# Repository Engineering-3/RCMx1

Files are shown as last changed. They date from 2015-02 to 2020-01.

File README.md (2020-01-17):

RCMx1
========================

RCMx1

This is an interface board for the RCM Control Stack that accommodates inputs (sensors) and outputs (motors, servos, LEDs) and communication through UART, SPI and I2C. Please see [Engineering3](http://engineering3.org/) for more information on the complete RCM Control Stack project.

Repository Contents
-------------------

* **/board** Eagle schematic/board files, gerbers, BOM
* **/firmware** Microcontroller firmware build files

Version History
---------------
* [RCMx1 Board v03](https://github.com/Engineering-3/RCMx1/tree/master/board/RCMx1_v03) First public hardware version - version 3 
* [RCMx1 Firmware v07](https://github.com/Engineering-3/RCMx1/tree/master/firmware) First public firmware version - version 7

License Information
-------------------
Hardware is released under [Solderpad Hardware License v0.51](http://solderpad.org/licenses/SHL-0.51/).
Firmware is released under [GNU GPL v2](http://www.gnu.org/licenses/old-licenses/gpl-2.0.html).
Distributed as-is; no warranty is given.

Getting Started Help
--------------------
Follow the [RCMx1 User Guide](https://github.com/Engineering-3/RCMx1/blob/master/firmware/docs/RCMx1%20User%20Guide.doc) here in the repo.

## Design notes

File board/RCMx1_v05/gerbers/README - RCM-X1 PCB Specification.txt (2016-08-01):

RCM-X1 PCB Specification
-------------------------------

BOARD STACK:

1. Copper Top
2. Copper Bottom

SILKSCREENS:

1.  Both Layers

PASTE MASKS:

1. Top Layer

BOARD MATERIALS:

RoHS Compliant: YES
Copper: 1oz
Finish: Immersion Gold
Material: FR-406
Thickness: 62 mil
Tg>170
Soldermask: SMOBC BLUE
Silkscreen: White

BOARD TESTING:

Electrical Test: YES

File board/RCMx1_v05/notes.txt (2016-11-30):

Got version RCMx1_v01 from Tim (who got it from Jim) - 10/29/2014.

Updated to v02 with the following changes: (10/29/2014 - BPS - Schmalz Haus)
* Changed fiducal marks so they had the copper restrict layer pulling back the copper the full 0.04".
* Changed R19 from 499K to 499 ohms (error only in DigiKey Part Number field of BOM)

Updated to v03 with the following changes: (02/13/2015 - BPS - Schmalz Haus)
* Added OSHW logo to schematic and board silk layer (done)
* Added Solderpad license to schematic (done)
* Added Copyright to schematic and silk layer (done)
* Added ROSH symbol to board silk layer (done)

Updated to v04 with the following changes: (02/28/2016 - BPS - Schmalz Haus)
* Added OSHW logo to the bottom silk layer
* Added RoSH symbol to the bottom silk layer
* Added "http://engineering3.org" and "RoSH Compliant" to bottom silk layer
* Updated rev text on top silk
* Updated copyright dates to 2016 on schematic and board silk

Updated to v05 with the following changes: (11/29/2016 - BPS - Schmalz Haus)
* Fixed pin one silk screen for J7 (ICSP header)

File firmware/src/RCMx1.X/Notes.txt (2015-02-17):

Notes on RCMx1 when doing firmware bringup.

* Wrong processor used - need the larger part (get part number for Jim) with PWM 9 and 10
* Silk screen for GPIO and Analog needs to be re-thought
* Mapping of analog and GPIO needs to be updated - create map of current code for Tim and approve
* ADC values should never be able to go negative.
*

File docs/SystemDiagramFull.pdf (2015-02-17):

## SRV, RadioBoard, RCMx1 System Diagram

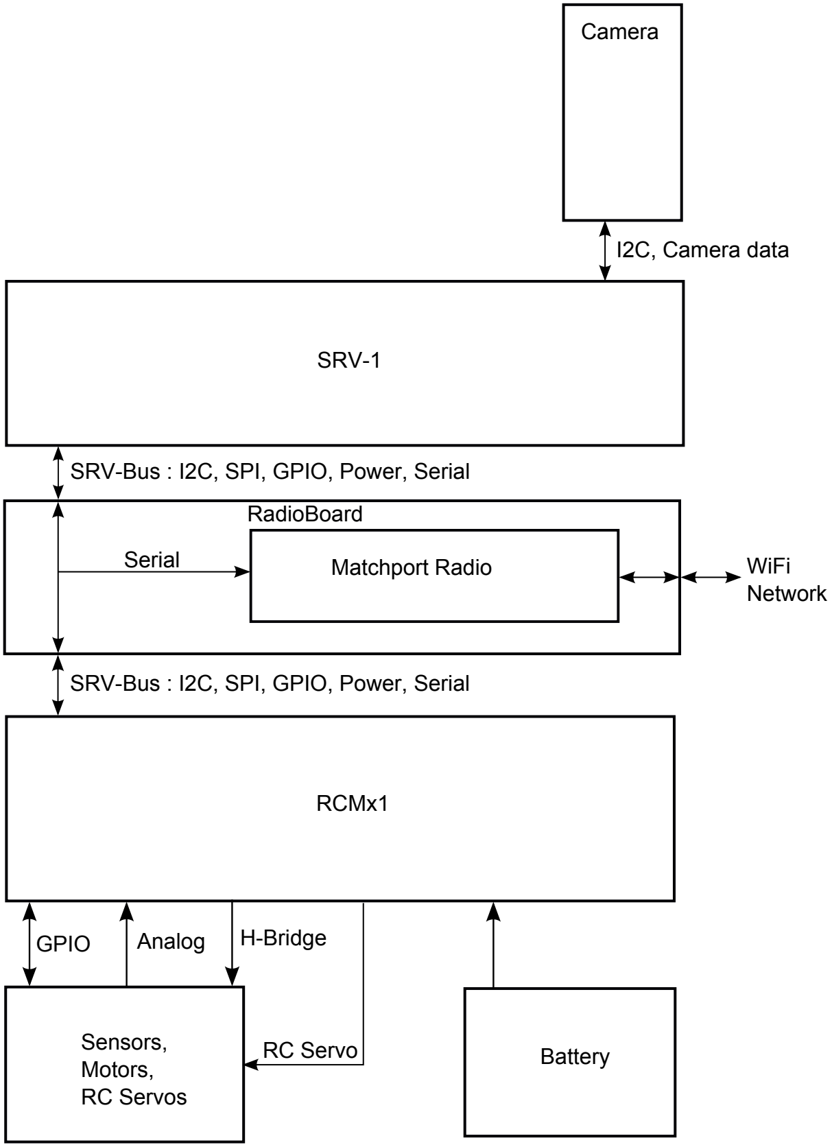
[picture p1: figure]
Camera; SRV-1; RadioBoard; RCMx1; Battery Sensors, Motors, RC Servos; GPIO; Analog; H-Bridge; RC Servo; SRV-Bus : I2C, SPI, GPIO, Power, Serial; WiFi Network; Serial; Matchport Radio; I2C, Camera data

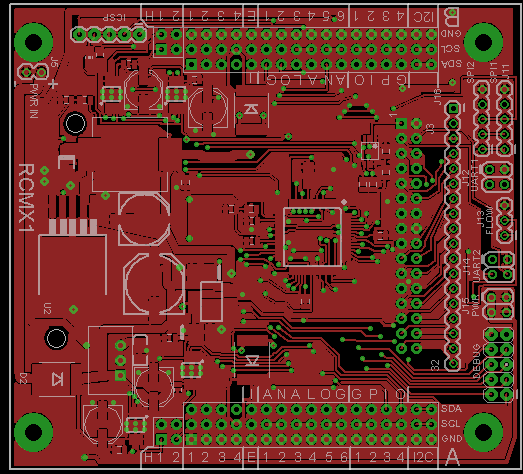
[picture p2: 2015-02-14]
board/BPS2.png

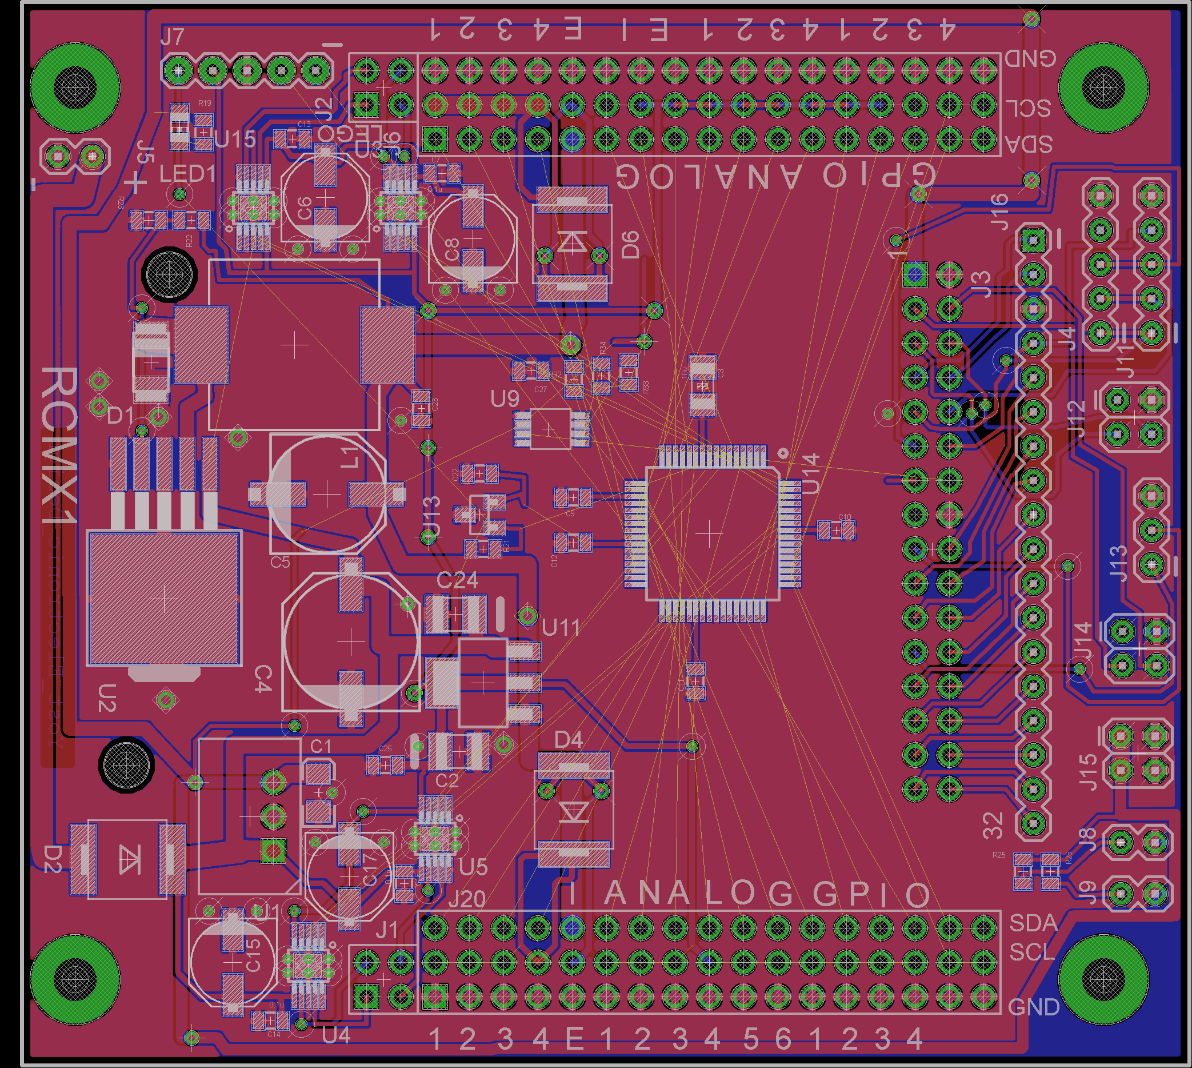
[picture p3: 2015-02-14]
board/RCMX1 8_15_12.png

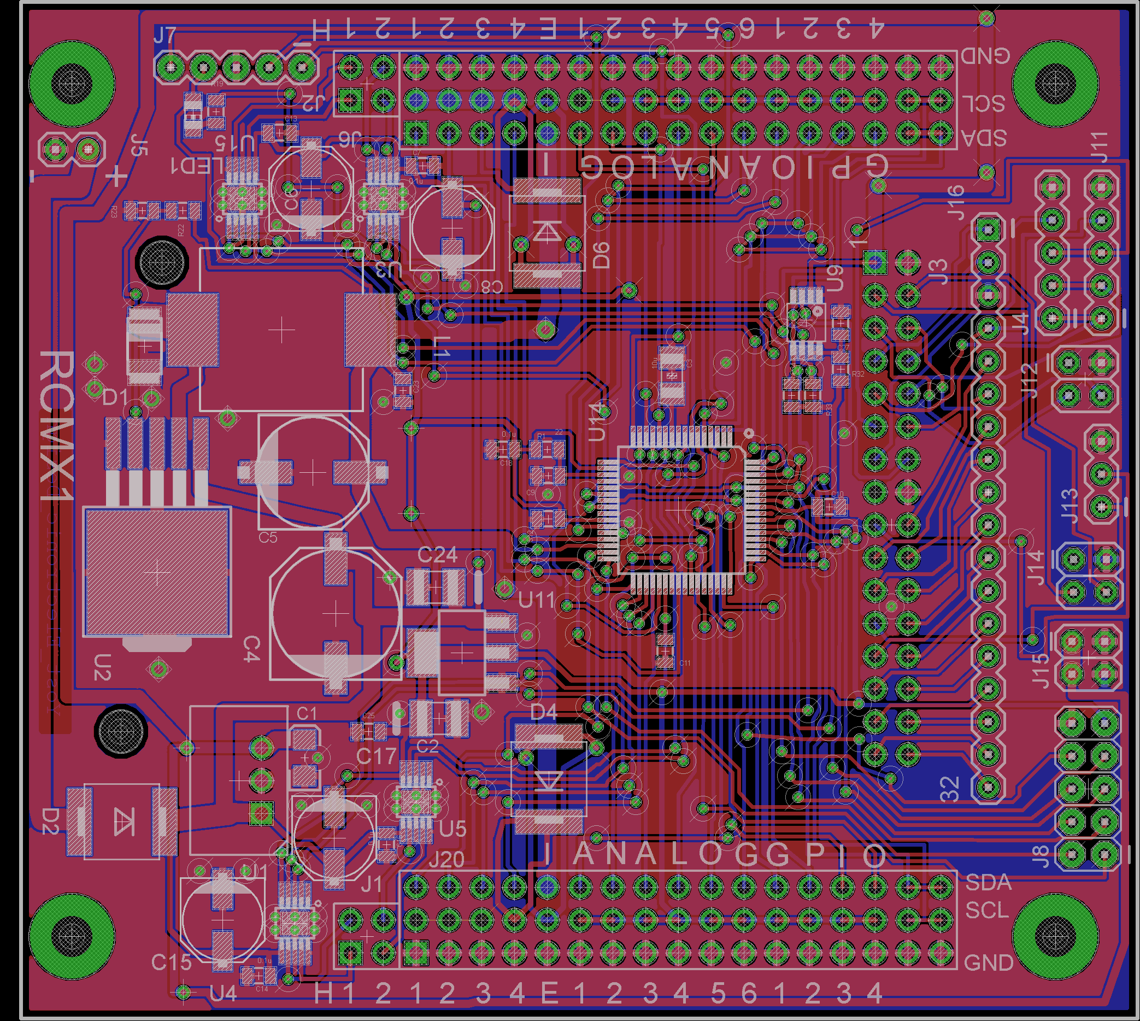
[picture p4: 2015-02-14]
board/RCMX1 9_10_12 Final.png

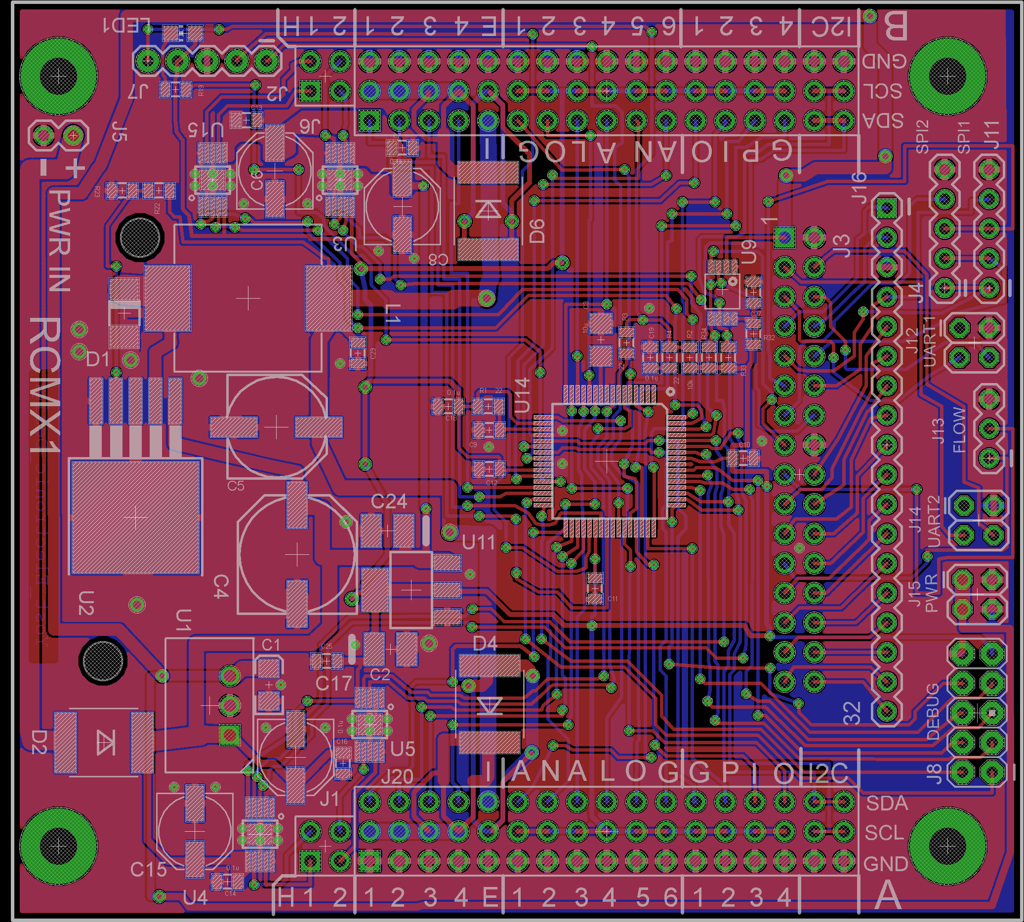
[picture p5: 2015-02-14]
board/RCMX1 FINAL.png

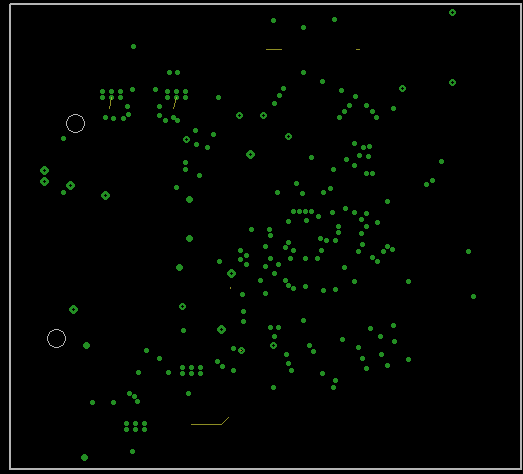
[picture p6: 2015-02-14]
board/RCMX1_BPS_Airwires.png

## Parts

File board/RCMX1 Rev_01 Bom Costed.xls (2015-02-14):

RCMX1 BOM | Rev_01 | 2014-05-28
Yost Electronic Design
James Yost - jamesyost12@yahoo.com
612-308-3487
 |  |  |  | Individual Component Cost |  |  |  |  |  | Cost at BOM Quantity
Reference Designator | Value | Digikey Part Number | Qty | 1 | 50 | 100 | 1000 | Notes |  | 1 | 50 | 100 | 1000
C1 | 10u | 445-1602-1-ND | 1 | $0.33 | $0.33 | $0.20 | $0.08 |  | x | $0.33 | $0.33 | $0.20 | $0.08
C3 | 10uF, X7R | 445-4042-1-ND | 1 | $0.35 | $0.35 | $0.15 | $0.10 | Ceramic X7R
C4 | 470u, 25V | PCE4440CT-ND | 1 | $1.20 | $0.82 | $0.74 | $0.64 |  | x | $1.20 | $0.82 | $0.74 | $0.64
C5 | 470u, 10V | PCE4526CT-ND | 1 | $1.05 | $0.71 | $0.65 | $0.56 |  | x | $1.05 | $0.71 | $0.65 | $0.56
C2 | 47uF | 478-3891-1-ND | 1 | $0.88 | $0.76 | $0.67 | $0.44 |  | x | $0.88 | $0.76 | $0.67 | $0.44
C7,10,11,12,13,14,18,19,23,25,27 | 0.1uF, 25V, X7R | 490-1673-1-ND | 11 | $0.06 | $0.05 | $0.04 | $0.01 |  | x | $0.66 | $0.53 | $0.40 | $0.14
C6, 8, 15, 17 | 100uF, ELT, 35V | PCE3951CT-ND | 4 | $0.63 | $0.36 | $0.30 | $0.19 |  |  | $2.52
C9 | 0.22u | 399-3491-1-ND | 1 | $0.14 | $0.06 | $0.04 | $0.03 |  | x | $0.14 | $0.06 | $0.04 | $0.03
C24 | 22uF, Y5V | 445-3478-1-ND (http://search.digikey.com/scripts/DkSearch/dksus.dll?Detail&name=445-3478-1-ND) | 1 | $0.63 | $0.50 | $0.30 | $0.19 |  | x | $0.63 | $0.50 | $0.30 | $0.19
D1 | B340LA | B340LA-FDICT-ND | 1 | $0.61 | $0.48 | $0.36 | $0.21 |  | x | $0.61 | $0.48 | $0.36 | $0.21
D2,4,6 | Schottky Diode, 35V, 10A | SK1035-TPCT-ND (http://search.digikey.com/scripts/DkSearch/dksus.dll?Detail&name=SK1035-TPCT-ND) | 3 | $1.00 | $0.85 | $0.72 | $0.47 |  | x | $3.00 | $2.55 | $2.17 | $1.42
J1,2 | 2x2 0.1" spacing, hdr | TSW-102-23-T-D (Samtec) | 2 | $0.14 | $0.14 | $0.14 | $0.14 | LEGO H-Bridge | x | $0.28 | $0.28 | $0.28 | $0.28
J3 | 2x16 0.1" spacing, hdr | ESQ-116-37-G-D (Samtec) | 1 | $3.62 | $3.62 | $3.62 | $3.00 | Was ESQ-116-39-G-D (Samtec) | z | $3.62 | $3.62 | $3.62 | $3.00
J4,7,11 | 1x5 0.1" spacing, hdr | TSW-105-23-T-S (Samtec) | 3 | $0.18 | $0.18 | $0.18 | $0.18 |  |  | $0.53
J6, 20 | 3x17 0.1" spacing, hdr | TSW-117_23-T-T (Samtec) | 2 | $1.98 | $1.98 | $1.98 | $1.65 |  |  | $3.96
J13 | 1x3 0.1" spacing, hdr | TSW-103-23-T-S (Samtec) | 2 | $0.16 | $0.16 | $0.16 | $0.16 | Flow ctr, batt mon select | z | $0.32 | $0.32 | $0.32 | $0.32
J5 | 1x2 0.1" spacing, hdr, RA | WM4924-ND(optional part see line 29) | 1 | $0.19 | $0.05 | $0.04 | $0.02 | Main Power In, Right Angle | z | $0.19 | $0.05 | $0.04 | $0.02
J8 | 2x5 0.1" spacing, hdr | TSW-105-23-T-D (Samtec) | 1 | $0.35 | $0.35 | $0.35 | $0.35 |  |  | $0.35
JX | 1x2 0.1 spacing extended | ESQ-102-37-G-S (Samtec) | 1 | $0.48 | $0.48 | $0.48 | $0.48 | Extended Power Input | x | $0.48 | $0.48 | $0.48 | $0.48
J5 | 1x2 0.1" spacing, hdr | TSW-102-23-T-S (Samtec) | 1 | $0.07 | $0.06 | $0.06 | $0.06 | J5 was A19450-ND | z | $0.07 | $0.06 | $0.06 | $0.06
J12,14 | 2x2 0.1" socket pol pin1 | SSW-102-01-T-D-001 | 2 | $0.49 | $0.43 | $0.43 | $0.43 |  | z | $0.98 | $0.86 | $0.86 | $0.86
J15 | 2x2 0.1" spacing, hdr | TSW-102-07-T-D | 1 | $0.13 | $0.10 | $0.10 | $0.10 |  | z | $0.13 | $0.10 | $0.10 | $0.10
J16 | 1x18 0.1" spacing, hdr | TSW-118-07-T-S | 1 | $0.63 | $0.52 | $0.52 | $0.52 |  | x | $0.63 | $0.52 | $0.52 | $0.52
L1 | 47uH | 513-1050-6-ND | 1 | $1.88 | $1.88 | $1.27 | $1.27 |  | x | $1.88 | $1.88 | $1.27 | $1.27
LED1 | LED RED CLEAR THIN | 160-1427-1-ND | 1 | $0.53 | $0.53 | $0.22 | $0.11 |  | x | $0.53 | $0.53 | $0.22 | $0.11
R1,3,4 | 22 | RHM22.0CCT-ND | 3 | $0.04 | $0.03 | $0.03 | $0.02 |  | x | $0.12 | $0.08 | $0.08 | $0.05
R2 | 10k | RHM10.0KCRCT-ND | 1 | $0.04 | $0.03 | $0.03 | $0.02 |  | x | $0.04 | $0.03 | $0.03 | $0.02
R33,34 | 2.21k | RHM2.21KCRCT-ND | 2 | $0.08 | $0.05 | $0.05 | $0.04 |  | x | $0.16 | $0.11 | $0.11 | $0.07
R19 | 499 | RHM499KCRCT-ND | 2 | $0.08 | $0.05 | $0.05 | $0.04 |  | x | $0.16 | $0.11 | $0.11 | $0.07
R23 | 1k | RHM1.00KCRCT-ND | 1 | $0.04 | $0.03 | $0.03 | $0.02 |  | x | $0.04 | $0.03 | $0.03 | $0.02
R22 | 3.9k | RHM3.90KCRCT-ND (http://search.digikey.com/scripts/DkSearch/dksus.dll?Detail&name=RHM39.0KCRCT-ND) | 1 | $0.04 | $0.03 | $0.03 | $0.02 |  | x | $0.04 | $0.03 | $0.03 | $0.02
R32 | 200k | RHM200KCRCT-ND | 1 | $0.04 | $0.03 | $0.03 | $0.02 |  | x | $0.04 | $0.03 | $0.03 | $0.02
U1 | Recom 3.3V Regulator | 945-1036-ND | 1 | $9.20 | $7.77 | $7.15 | $6.54 |  | x | $9.20 | $7.77 | $7.15 | $6.54
U2 | DC-DC Conv Var, 5A | AP1501A-K5LDICT-ND | 1 | $5.94 | $5.34 | $4.35 | $3.96 | Adjustable 5Amp regulator | x | $5.94 | $5.34 | $4.35 | $3.96
U3,4,5,15 | IC PWM MOTOR DVR FULL 10-MSOP | 620-1451-1-ND | 4 | $2.20 | $1.78 | $1.60 | $1.03 | LEGO H-Bridge |  | $8.80 | $7.12 | $6.40 | $4.11
U9 | Level Translator, 3.3V-5V, 2 Bit | 296-18509-1-ND (http://search.digikey.com/scripts/DkSearch/dksus.dll?Detail&name=296-18509-1-ND) | 1 | $0.99 | $0.78 | $0.70 | $0.43 | I2C Level Translator | x | $0.99 | $0.78 | $0.70 | $0.43
U14 | IC MCU 8BIT 64KB FLASH 64TQFP | PIC18F66K22-I/PT-ND (http://www.digikey.com/product-detail/en/PIC18F66K22-I%2FPT/PIC18F66K22-I%2FPT-ND/2712354) | 1 | $4.46 | $3.41 | $3.09 | $3.09 |  | x | $4.46 | $3.41 | $3.09 | $3.09
U11 | LDO REG 800MA 5V SOT223 | 296-21114-1-ND | 1 | $0.70 | $0.54 | $0.48 | $0.28 |  | x | $0.70 | $0.54 | $0.48 | $0.28
PCB | Bare PCB - no shipping | China- Excludes $35 one time tooling chg | 1 | $19.11 | $1.62 | $1.17 | $0.69 |  | z | $19.11 | $1.62 | $1.17 | $0.69
 |  |  | Parts | 1ea | 50ea | 100ea | 1000ea |  |  | 1ea | 50ea | 100ea | 1000ea
 |  | Component Cost Totals | 67 | $60.65 | $37.21 | $32.50 | $27.57 | Component Cost Quantity Totals |  | $74.75 | $42.41 | $37.04 | $30.11
Finished Product Costing
Parts and Labor |  | Andrew Technologies |  |  | ? | ?
 |  | Note: Price includes NRE charges |  |  | ? | ?
BOM UPDATES
2014-05-28 | Changed From | To
 | PIC18F65K22-I/PTRSL-ND | PIC18F66K22-I/PT-ND (http://www.digikey.com/product-detail/en/PIC18F66K22-I%2FPT/PIC18F66K22-I%2FPT-ND/2712354)
 | J5, A19450-ND, 1x2 0.1" spacing, hdr | WM4924-ND (http://search.digikey.com/scripts/DkSearch/dksus.dll?WT.z_header=search_go&lang=en&site=us)

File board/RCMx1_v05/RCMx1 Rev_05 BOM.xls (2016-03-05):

RCMX1 BOM | Rev_04 | 2016-02-28
Yost Electronic Design
James Yost - jamesyost12@yahoo.com
612-308-3487
Reference Designator | Value | Digikey Part Number | Qty | Notes
C1 | 10u | 445-1602-1-ND | 1
C3 | 10uF, X7R | 445-4042-1-ND | 1 | Ceramic X7R
C4 | 470u, 25V | PCE4440CT-ND | 1
C5 | 470u, 10V | PCE4526CT-ND | 1
C2 | 47uF | 478-3891-1-ND | 1
C7,10,11,12,13,14,18,19,23,25,27 | 0.1uF, 25V, X7R | 490-1673-1-ND | 11
C6, 8, 15, 17 | 100uF, ELT, 35V | PCE3951CT-ND | 4
C9 | 0.22u | 399-3491-1-ND | 1
C24 | 22uF, X5R, 25V | 399-11405-1-ND (http://www.digikey.com/product-detail/en/C1210C226M3PACTU/399-11405-1-ND/4747719) | 1
D1 | B340LA | B340LA-FDICT-ND | 1
D2,4,6 | Schottky Diode, 35V, 10A | SK1035-TPCT-ND (http://search.digikey.com/scripts/DkSearch/dksus.dll?Detail&name=SK1035-TPCT-ND) | 3
J1,2 | 2x2 0.1" spacing, hdr | TSW-102-23-G-D (Samtec) | 2 | LEGO H-Bridge
J3 | 2x16 0.1" spacing, hdr | ESQ-116-37-G-D (Samtec) | 1 | Was ESQ-116-39-G-D (Samtec)
J4,7,11 | 1x5 0.1" spacing, hdr | TSW-105-23-G-S (Samtec) | 3
J6, 20 | 3x17 0.1" spacing, hdr | TSW-117-23-G-T (Samtec) | 2
J13 | 1x3 0.1" spacing, hdr | TSW-103-23-G-S (Samtec) | 2 | Flow ctr, batt mon select
J5 | 1x2 0.1" spacing, hdr, RA | WM4900-ND (DigiKey) | 1 | Main Power In, Right Angle
J8 | 2x5 0.1" spacing, hdr | TSW-105-23-G-D (Samtec) | 1
J12,14 | 2x2 0.1" socket pol pin1 | SSW-102-01-G-D-001 (Samtec) | 2
J15 | 2x2 0.1" spacing, hdr | TSW-102-07-G-D (Samtec) | 1
J16 | 1x18 0.1" spacing, hdr | TSW-118-07-G-S (Samtec) | 1
L1 | 47uH | 513-1050-6-ND | 1
LED1 | LED RED CLEAR THIN | 160-1427-1-ND | 1
R1,3,4 | 22 | RHM22.0CCT-ND | 3
R2 | 10k | RHM10.0KCRCT-ND | 1
R33,34 | 2.21k | RHM2.21KCRCT-ND | 2
R19 | 499 | RHM499CRCT-ND | 2
R23 | 1k | RHM1.00KCRCT-ND | 1
R22 | 3.9k | RHM3.90KCRCT-ND (http://search.digikey.com/scripts/DkSearch/dksus.dll?Detail&name=RHM39.0KCRCT-ND) | 1
R32 | 200k | RHM200KCRCT-ND | 1
U1 | Recom 3.3V Regulator | 945-1036-ND | 1
U2 | DC-DC Conv Var, 5A | AP1501A-K5LDICT-ND | 1 | Adjustable 5Amp regulator
U3,4,5,15 | IC PWM MOTOR DVR FULL 10-MSOP | 620-1451-1-ND | 4 | LEGO H-Bridge
U9 | Level Translator, 3.3V-5V, 2 Bit | 296-18509-1-ND (http://search.digikey.com/scripts/DkSearch/dksus.dll?Detail&name=296-18509-1-ND) | 1 | I2C Level Translator
U14 | IC MCU 8BIT 64KB FLASH 64TQFP | PIC18F66K22-I/PT-ND (http://www.digikey.com/product-detail/en/PIC18F66K22-I%2FPT/PIC18F66K22-I%2FPT-ND/2712354) | 1
U11 | LDO REG 800MA 5V SOT223 | 296-21114-1-ND | 1
PCB | Bare PCB - no shipping | China- Excludes $35 one time tooling chg | 1
 |  |  | Parts
 |  | Component Cost Totals | 65 | Component Cost Quantity Totals
Finished Product Costing
Parts and Labor |  | Andrew Technologies
 |  | Note: Price includes NRE charges
BOM UPDATES
2014-05-28 | Changed From | To
 | PIC18F65K22-I/PTRSL-ND | PIC18F66K22-I/PT-ND (http://www.digikey.com/product-detail/en/PIC18F66K22-I%2FPT/PIC18F66K22-I%2FPT-ND/2712354)
 | J5, A19450-ND, 1x2 0.1" spacing, hdr | WM4924-ND (http://search.digikey.com/scripts/DkSearch/dksus.dll?WT.z_header=search_go&lang=en&site=us)
2014-06-16 | C24, 22uF Y5V, 445-3478-1-ND (http://search.digikey.com/scripts/DkSearch/dksus.dll?Detail&name=445-3478-1-ND) | 399-11405-1-ND (http://www.digikey.com/product-detail/en/C1210C226M3PACTU/399-11405-1-ND/4747719)

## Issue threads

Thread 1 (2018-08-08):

PWM/Servo Filter Edits

E3t1jump, 2018-08-08:
We need to finalize implementation of the PWM/Servo Filter functions. In the attached document the needed segments are highlighted:

Yellow: Elements that need to be Implemented
Teal: Example code that needs to be verified
Red: I don't quite remember, but maybe "red" to let us know these do not yet work?

[PWM_ServoFilter Edits.pdf](https://github.com/Engineering-3/RCMx1/files/2270652/PWM_ServoFilter.Edits.pdf)

EmbeddedMan, 2018-08-08:
Fantastic - this is very clear and should be relatively easy to implement.

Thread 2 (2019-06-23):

Servo Ports 35 and 36 do not recognize "0" as turn-off-power as do all the other servo ports.

EmbeddedMan, 2019-06-23:

EmbeddedMan, 2019-06-23:
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

I have been unable to reproduce this problem so far. This image shows all 8 servo outputs in their default bootup state (outputting 1.5ms pulses). I then execute the following PicoC program, which writes 0x00s to each of the servos, and then all of the outputs turn off.

writei2c(0x1C, 0x31, 0x00);
writei2c(0x1C, 0x32, 0x00);
writei2c(0x1C, 0x33, 0x00);
writei2c(0x1C, 0x34, 0x00);
writei2c(0x1C, 0x35, 0x00);
writei2c(0x1C, 0x36, 0x00);
writei2c(0x1C, 0x37, 0x00);
writei2c(0x1C, 0x38, 0x00);
exit(1);

EmbeddedMan, 2019-06-23:
Does this problem only happen when there are other sequences of I2C data sent to the RCMx1 first? @E3t1jump

E3t1jump, 2019-06-23:
I moved a different servo to Port 35 and it worked with 0x00 as power off. I'm now suspecting it is the two servos (maybe a different model). I will swap these for some others I have and report back.

E3t1jump, 2019-06-23:
Confirmed; it is something up with the servos and not the RCMx1. Two new servos work as expected.

Closed 2019-06-23.

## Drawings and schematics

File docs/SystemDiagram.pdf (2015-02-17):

## RCMx1 System Diagram

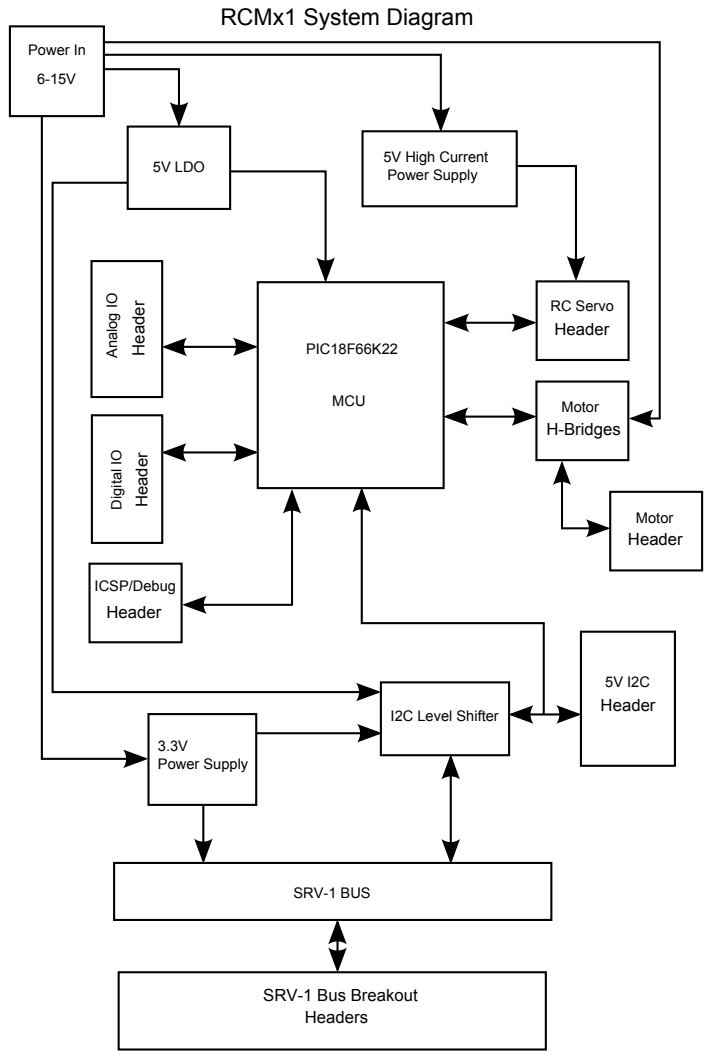
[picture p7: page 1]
PIC18F66K22; MCU; SRV-1 BUS; Power In; RC Servo; 5V High Current Power Supply; I2C Level Shifter; 5V LDO; 3.3V Power Supply; ICSP/Debug; Header; Header Header; Motor Header; Motor H-Bridges

Analog IO Digital IO

SRV-1 Bus Breakout
Headers

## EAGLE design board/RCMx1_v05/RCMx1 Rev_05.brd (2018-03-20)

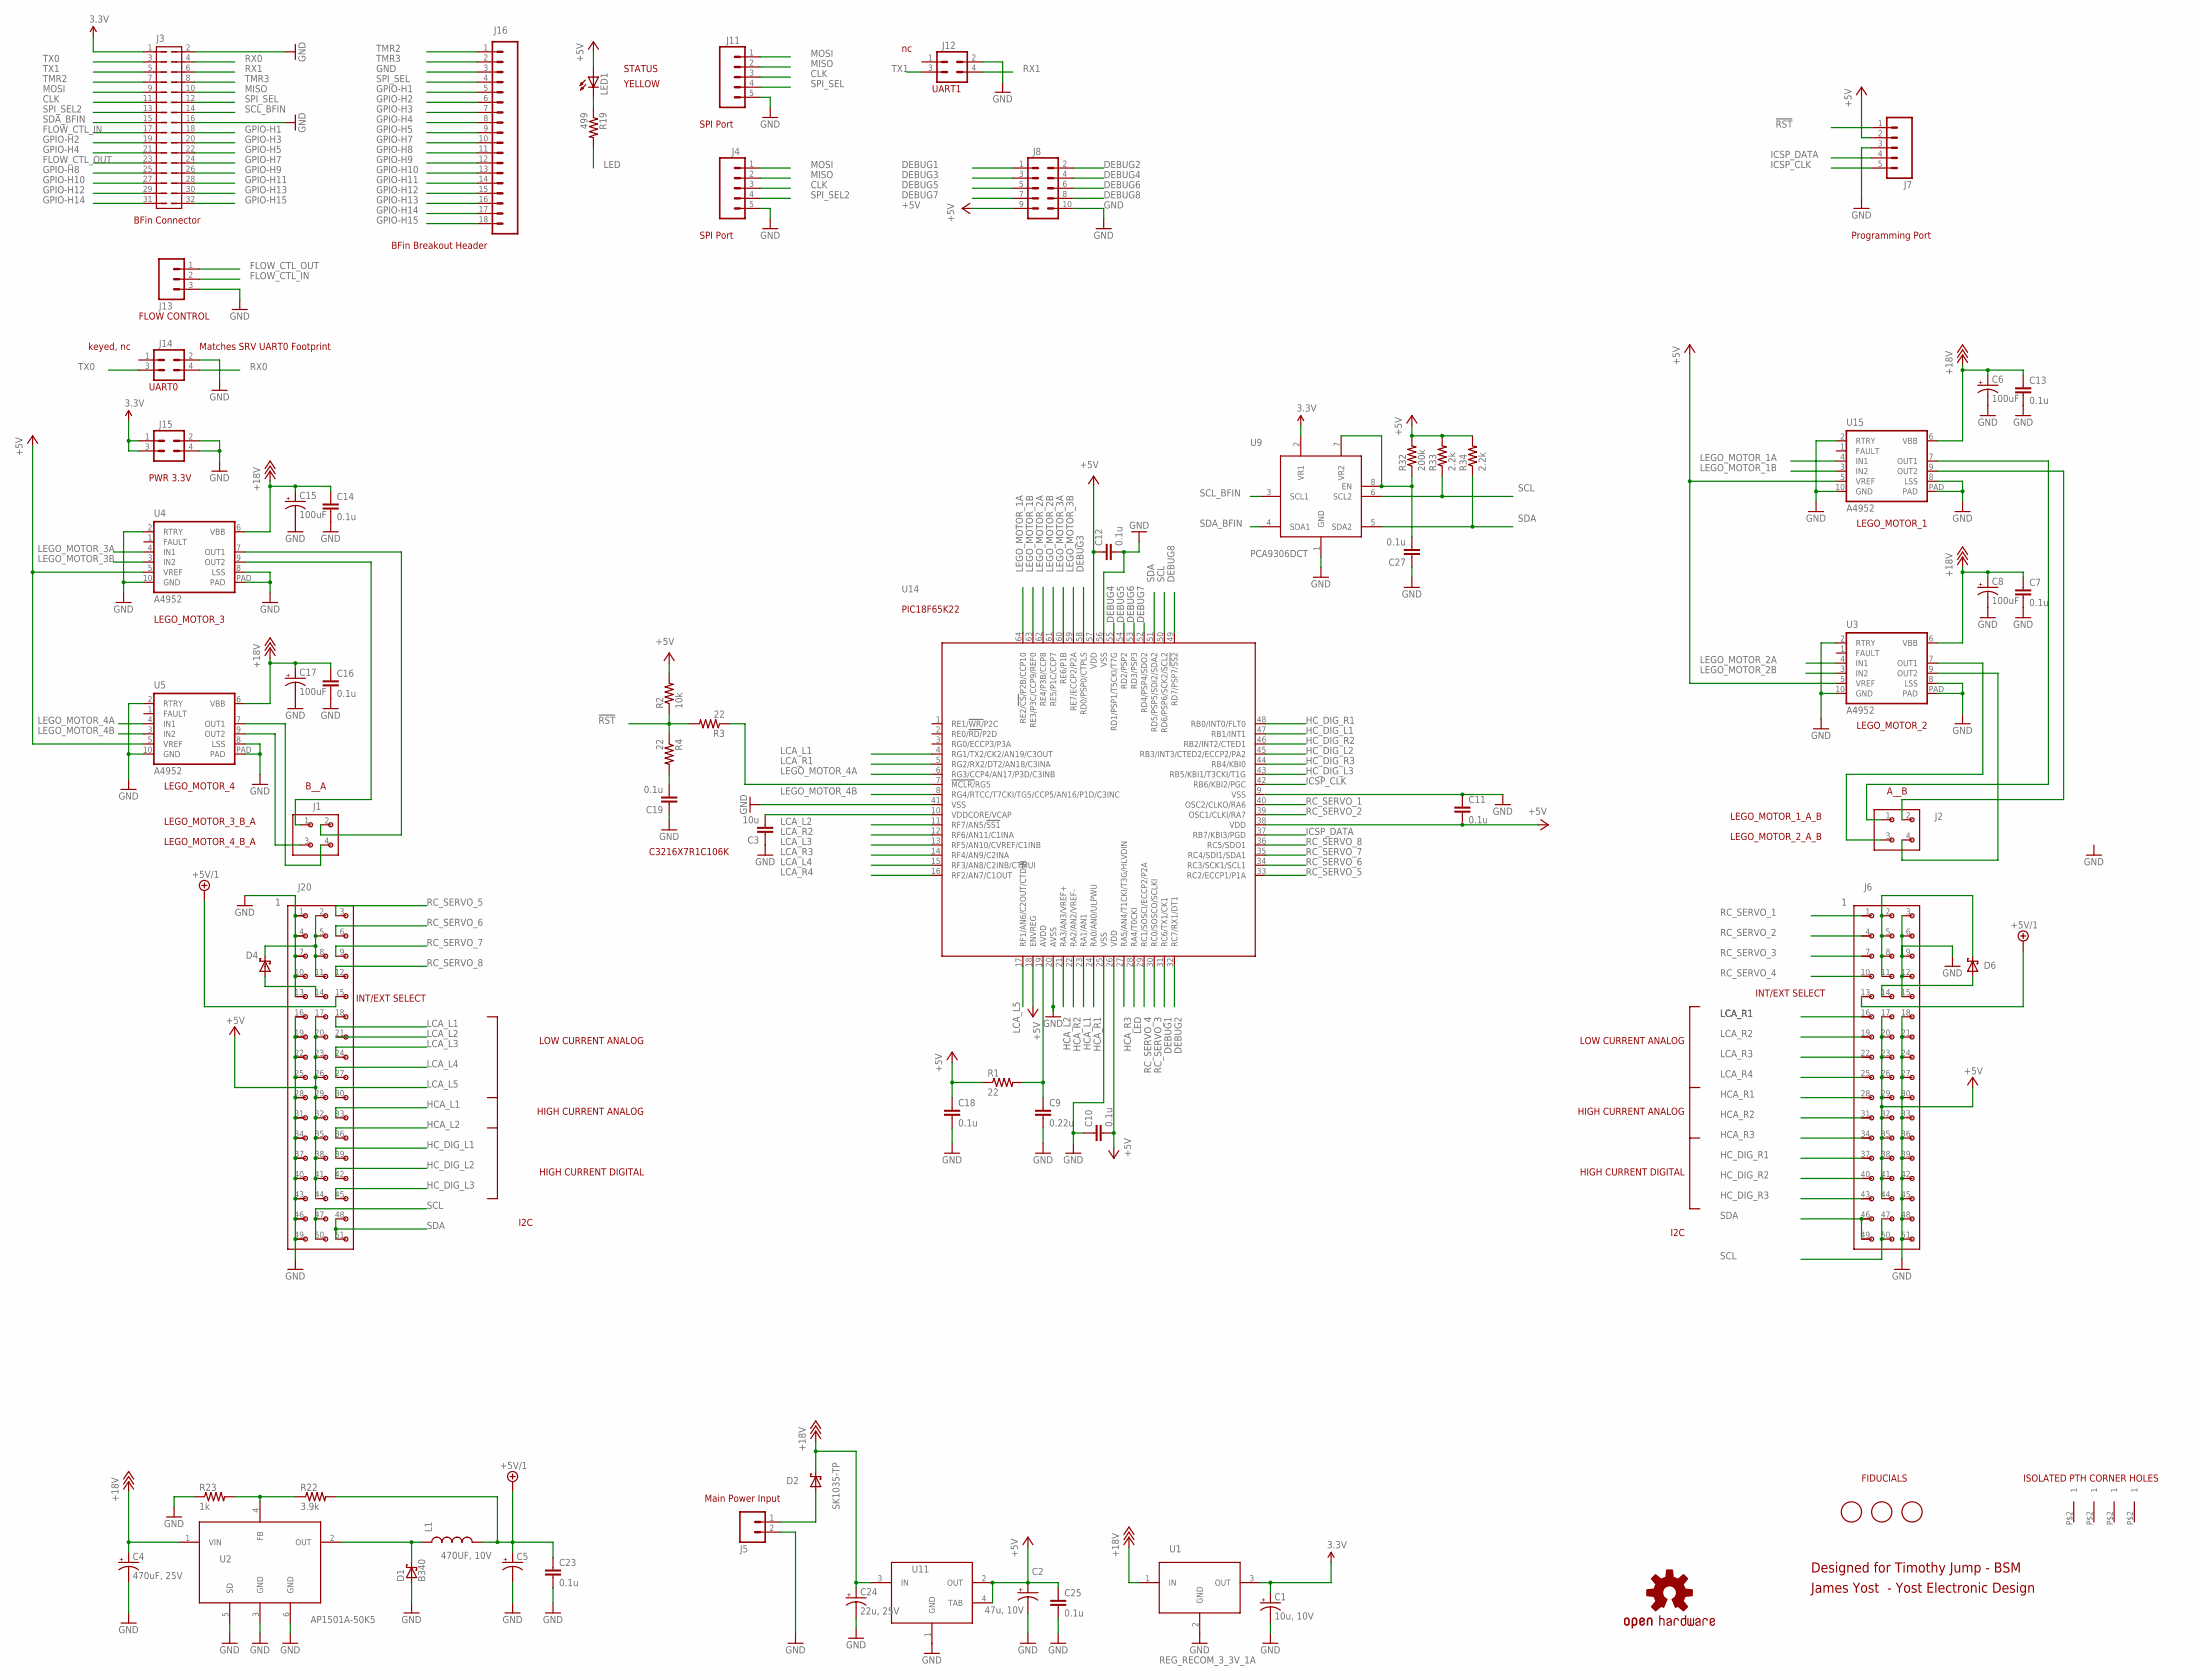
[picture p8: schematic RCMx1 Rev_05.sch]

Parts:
C1: 10u, 10V; EIA3216
C2: 47u, 10V; CAP1210_POL
C3: 10u; 1206
C4: 470uF, 25V; PANASONIC_G
C5: 470UF, 10V; PANASONIC_F
C6, C8, C15, C17: 100uF; PANASONIC_D
C7, C10, C11, C12, C13, C14, C16, C18, C19, C23, C25, C27: 0.1u; 0805
C9: 0.22u; 0805
C24: 22u, 25V; CAP1210_POL
D1: B340; SMA_DO214AC
D2, D4, D6: SK1035-TP; DO214AB
FID1, FID2, FID3: FIDUCIAL; FIDUCIAL_1MM
J1, J2: CON_2X2_0_100
J3: CON_2X16_0_100
J4, J7, J11: M05PTH; 1X05
J5: M02NG; 1X02
J6, J20: CON_3X17_0_100
J8: M05X2PTH; AVR_ICSP
J12, J14, J15: CON2X2
J13: M03PTH; 1X03
J16: CON1X18
L1: IND_47UH_COILTRONICS_2_95A; IND_PADS_SMT
LED1: LEDCHIP-LED0805; CHIP-LED0805
LOGO3: OSHW-LOGOM; OSHW-LOGO-M
R1, R3, R4: 22; 0805
R2: 10k; 0805
R19: 499; 0805
R22: 3.9k; 0805
R23: 1k; 0805
R32: 200k; 0805
R33, R34: 2.2k; 0805
U1: REG_RECOM_3_3V_1A
U2: AP1501A-50K5; TO263-5
U3, U4, U5, U15: A4952; MSOP10_W_THERMAL_PAD
U9: PCA9306DCT; TEST08
U11: TLV1117-5; SOT223
U14: MICRO_C_PIC18F65K22; 64PIN_TQFP_10X10X1MM
U$1, U$2, U$7, U$8: GNDPAD
U$3: ROHS_GARBAGE; ROHS_GARBAGE_5MM

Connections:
3.3V: C1.A (+), J3.1, J15.1, J15.3, U1.3 (OUT), U9.2 (VR1)
!RST: J7.1, R2.1, R3.2, R4.1
+5V: C2.1 (+), C10.2, C11.2, C12.1, C18.1, C25.1, J6.17, J6.20, J6.23, J6.26, J6.29, J6.32, J6.35, J6.38, J6.41, J6.44, J7.2, J8.9, J20.17, J20.20, J20.23, J20.26, J20.29, J20.32, J20.35, J20.38, J20.41, J20.44, LED1.A, R1.1, R2.2, R32.2, R33.2, R34.2, U3.5 (VREF), U4.5 (VREF), U5.5 (VREF), U11.2 (OUT), U11.4 (TAB), U14.18 (ENVREG), U14.26 (VDD), U14.38 (VDD), U14.57 (VDD), U15.5 (VREF)
+5V/1: C5.+, C23.1, J6.13, J20.15, L1.2, R22.2
+18V: C4.+, C6.+, C7.1, C8.+, C13.1, C14.1, C15.+, C16.1, C17.+, C24.1 (+), D2.1 (C), U1.1 (IN), U2.1 (VIN), U3.6 (VBB), U4.6 (VBB), U5.6 (VBB), U11.3 (IN), U15.6 (VBB)
CLK: J3.11, J4.3, J11.3
DEBUG1: J8.1, U14.31 (RC6/TX1/CK1)
DEBUG2: J8.2, U14.32 (RC7/RX1/DT1)
DEBUG3: J8.3, U14.58 (RD0/PSP0/CTPLS)
DEBUG4: J8.4, U14.55 (RD1/PSP1/T5CKI/T7G)
DEBUG5: J8.5, U14.54 (RD2/PSP2)
DEBUG6: J8.6, U14.53 (RD3/PSP3)
DEBUG7: J8.7, U14.52 (RD4/PSP4/SDO2)
DEBUG8: J8.8, U14.49 (RD7/PSP7/!SS2)
FLOW_CTL_IN: J3.17, J13.2
FLOW_CTL_OUT: J3.23, J13.1
GND: C1.C (-), C2.2 (-), C3.1, C4.-, C5.-, C6.-, C7.2, C8.-, C9.2, C10.1, C11.1, C12.2, C13.2, C14.2, C15.-, C16.2, C17.-, C18.2, C19.1, C23.2, C24.2 (-), C25.2, C27.1, D1.A, J3.2, J3.16, J4.5, J5.2, J6.3, J6.6, J6.9, J6.12, J6.15, J6.18, J6.21, J6.24, J6.27, J6.30, J6.33, J6.36, J6.39, J6.42, J6.45, J6.48, J6.51, J7.3, J8.10, J11.5, J12.2, J13.3, J14.2, J15.2, J15.4, J16.3, J20.1, J20.4, J20.7, J20.10, J20.13, J20.16, J20.19, J20.22, J20.25, J20.28, J20.31, J20.34, J20.37, J20.40, J20.43, J20.46, J20.49, R23.1, U1.2 (GND), U2.3 (GND), U2.5 (SD), U2.6 (GND), U3.2 (RTRY), U3.8 (LSS), U3.10 (GND), U3.PAD, U4.2 (RTRY), U4.8 (LSS), U4.10 (GND), U4.PAD, U5.2 (RTRY), U5.8 (LSS), U5.10 (GND), U5.PAD, U9.1 (GND), U11.1 (GND), U14.9 (VSS), U14.20 (AVSS), U14.25 (VSS), U14.41 (VSS), U14.56 (VSS), U15.2 (RTRY), U15.8 (LSS), U15.10 (GND), U15.PAD
GPIO-H1: J3.18, J16.5
GPIO-H2: J3.19, J16.6
GPIO-H3: J3.20, J16.7
GPIO-H4: J3.21, J16.8
GPIO-H5: J3.22, J16.9
GPIO-H7: J3.24, J16.10
GPIO-H8: J3.25, J16.11
GPIO-H9: J3.26, J16.12
GPIO-H10: J3.27, J16.13
GPIO-H11: J3.28, J16.14
GPIO-H12: J3.29, J16.15
GPIO-H13: J3.30, J16.16
GPIO-H14: J3.31, J16.17
GPIO-H15: J3.32, J16.18
HCA_L1: J20.33, U14.23 (RA1/AN1)
HCA_L2: J20.36, U14.21 (RA3/AN3/VREF+)
HCA_R1: J6.28, U14.24 (RA0/AN0/ULPWU)
HCA_R2: J6.31, U14.22 (RA2/AN2/VREF-)
HCA_R3: J6.34, U14.27 (RA5/AN4/T1CKI/T3G/HLVDIN)
HC_DIG_L1: J20.39, U14.47 (RB1/INT1)
HC_DIG_L2: J20.42, U14.45 (RB3/INT3/CTED2/ECCP2/PA2)
HC_DIG_L3: J20.45, U14.43 (RB5/KBI1/T3CKI/T1G)
HC_DIG_R1: J6.37, U14.48 (RB0/INT0/FLT0)
HC_DIG_R2: J6.40, U14.46 (RB2/INT2/CTED1)
HC_DIG_R3: J6.43, U14.44 (RB4/KBI0)
ICSP_CLK: J7.5, U14.42 (RB6/KBI2/PGC)
ICSP_DATA: J7.4, U14.37 (RB7/KBI3/PGD)
LCA_L1: J20.18, U14.4 (RG1/TX2/CK2/AN19/C3OUT)
LCA_L2: J20.21, U14.11 (RF7/AN5/!SS1)
LCA_L3: J20.24, U14.13 (RF5/AN10/CVREF/C1INB)
LCA_L4: J20.27, U14.15 (RF3/AN8/C2INB/CTMUI)
LCA_L5: J20.30, U14.17 (RF1/AN6/C2OUT/CTDIN)
LCA_R1: J6.16, U14.5 (RG2/RX2/DT2/AN18/C3INA)
LCA_R2: J6.19, U14.12 (RF6/AN11/C1INA)
LCA_R3: J6.22, U14.14 (RF4/AN9/C2INA)
LCA_R4: J6.25, U14.16 (RF2/AN7/C1OUT)
LED: R19.2, U14.28 (RA4/T0CKI)
LEGO_1A: J2.1, U15.7 (OUT1)
LEGO_1B: J2.2, U15.9 (OUT2)
LEGO_2A: J2.3, U3.7 (OUT1)
LEGO_2B: J2.4, U3.9 (OUT2)
LEGO_4A: J1.4, U5.7 (OUT1)
LEGO_4B: J1.3, U5.9 (OUT2)
LEGO_MOTOR_1A: U14.64 (RE2/!CS/!P2B/CCP10), U15.4 (IN1)
LEGO_MOTOR_1B: U14.63 (RE3/P3C/CCP9/REF0), U15.3 (IN2)
LEGO_MOTOR_2A: U3.4 (IN1), U14.62 (RE4/P3B/CCP8)
LEGO_MOTOR_2B: U3.3 (IN2), U14.61 (RE5/P1C/CCP7)
LEGO_MOTOR_3A: U4.4 (IN1), U14.60 (RE6/P1B)
LEGO_MOTOR_3B: U4.3 (IN2), U14.59 (RE7/ECCP2/P2A)
LEGO_MOTOR_4A: U5.4 (IN1), U14.6 (RG3/CCP4/AN17/P3D/C3INB)
LEGO_MOTOR_4B: U5.3 (IN2), U14.8 (RG4/RTCC/T7CKI/TG5/CCP5/AN16/P1D/C3INC)
MISO: J3.10, J4.2, J11.2
MOSI: J3.9, J4.1, J11.1
unnamed: D1.C, L1.1, U2.2 (OUT)
unnamed: R3.1, U14.7 (!MCLR/!RG5)
unnamed: D6.2 (A), J6.14
unnamed: D6.1 (C), J6.2, J6.5, J6.8, J6.11
unnamed: C19.2, R4.2
unnamed: D4.1 (C), J20.2, J20.5, J20.8, J20.11
unnamed: C9.1, R1.2, U14.19 (AVDD)
unnamed: D2.2 (A), J5.1
unnamed: J1.2, U4.7 (OUT1)
unnamed: J1.1, U4.9 (OUT2)
unnamed: R22.1, R23.2, U2.4 (FB)
unnamed: C3.2, U14.10 (VDDCORE/VCAP)
unnamed: D4.2 (A), J20.14
unnamed: C27.2, R32.1, U9.7 (VR2), U9.8 (EN)
unnamed: LED1.C, R19.1
RC_SERVO_1: J6.1, U14.40 (OSC2/CLKO/RA6)
RC_SERVO_2: J6.4, U14.39 (OSC1/CLKI/RA7)
RC_SERVO_3: J6.7, U14.30 (RC0/SOSCO/SCLKI)
RC_SERVO_4: J6.10, U14.29 (RC1/SOSCI/ECCP2/P2A)
RC_SERVO_5: J20.3, U14.33 (RC2/ECCP1/P1A)
RC_SERVO_6: J20.6, U14.34 (RC3/SCK1/SCL1)
RC_SERVO_7: J20.9, U14.35 (RC4/SDI1/SDA1)
RC_SERVO_8: J20.12, U14.36 (RC5/SDO1)
RX0: J3.4, J14.4
RX1: J3.6, J12.4
SCL: J6.47, J6.50, J20.47, J20.50, R33.1, U9.6 (SCL2), U14.50 (RD6/PSP6/SCK2/SCL2)
SCL_BFIN: J3.14, U9.3 (SCL1)
SDA: J6.46, J6.49, J20.48, J20.51, R34.1, U9.5 (SDA2), U14.51 (RD5/PSP5/SDI2/SDA2)
SDA_BFIN: J3.15, U9.4 (SDA1)
SPI_SEL: J3.12, J11.4, J16.4
SPI_SEL2: J3.13, J4.4
TMR2: J3.7, J16.1
TMR3: J3.8, J16.2
TX0: J3.3, J14.3
TX1: J3.5, J12.3

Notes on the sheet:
YELLOW
STATUS
BFin Connector
Programming Port
SPI Port
Main Power Input
UART1
FLOW CONTROL
PWR 3.3V
UART0
Matches SRV UART0 Footprint
keyed, nc
ISOLATED PTH CORNER HOLES
BFin Breakout Header
Designed for Timothy Jump - BSM
James Yost - Yost Electronic Design
INT/EXT SELECT
C3216X7R1C106K
LEGO_MOTOR_3
LEGO_MOTOR_4
LEGO_MOTOR_4_B_A
LEGO_MOTOR_3_B_A
B__A
LEGO_MOTOR_1
LEGO_MOTOR_2
LEGO_MOTOR_1_A_B
LEGO_MOTOR_2_A_B
A__B
LOW CURRENT ANALOG
HIGH CURRENT ANALOG
HIGH CURRENT DIGITAL
I2C
PIC18F65K22
FIDUCIALS

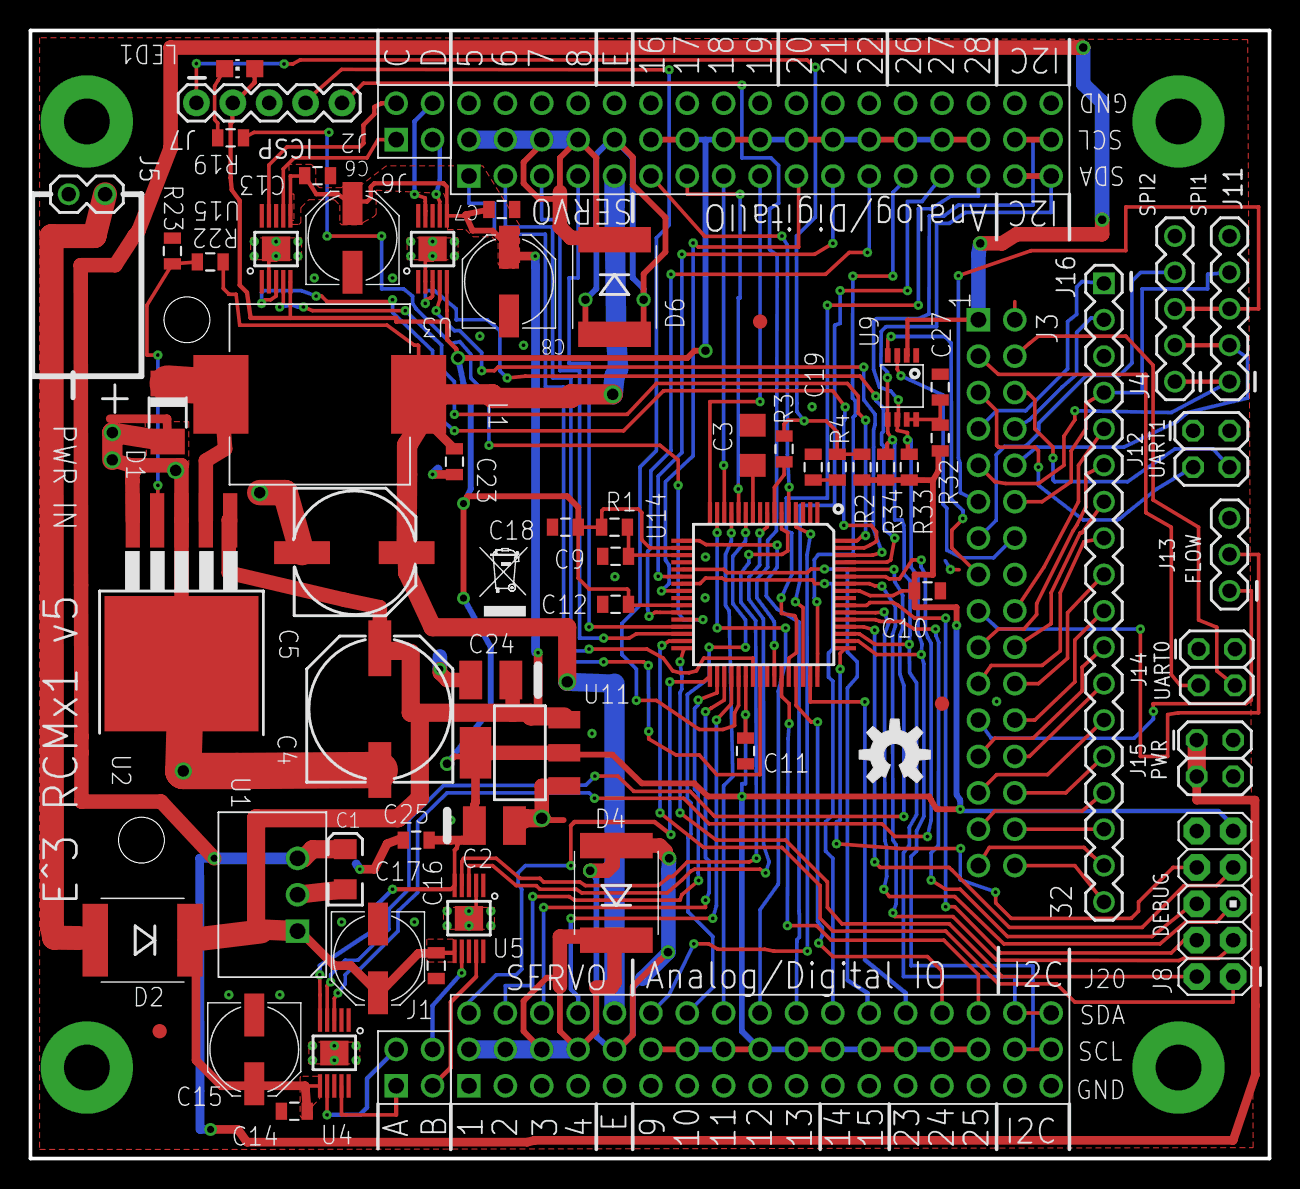
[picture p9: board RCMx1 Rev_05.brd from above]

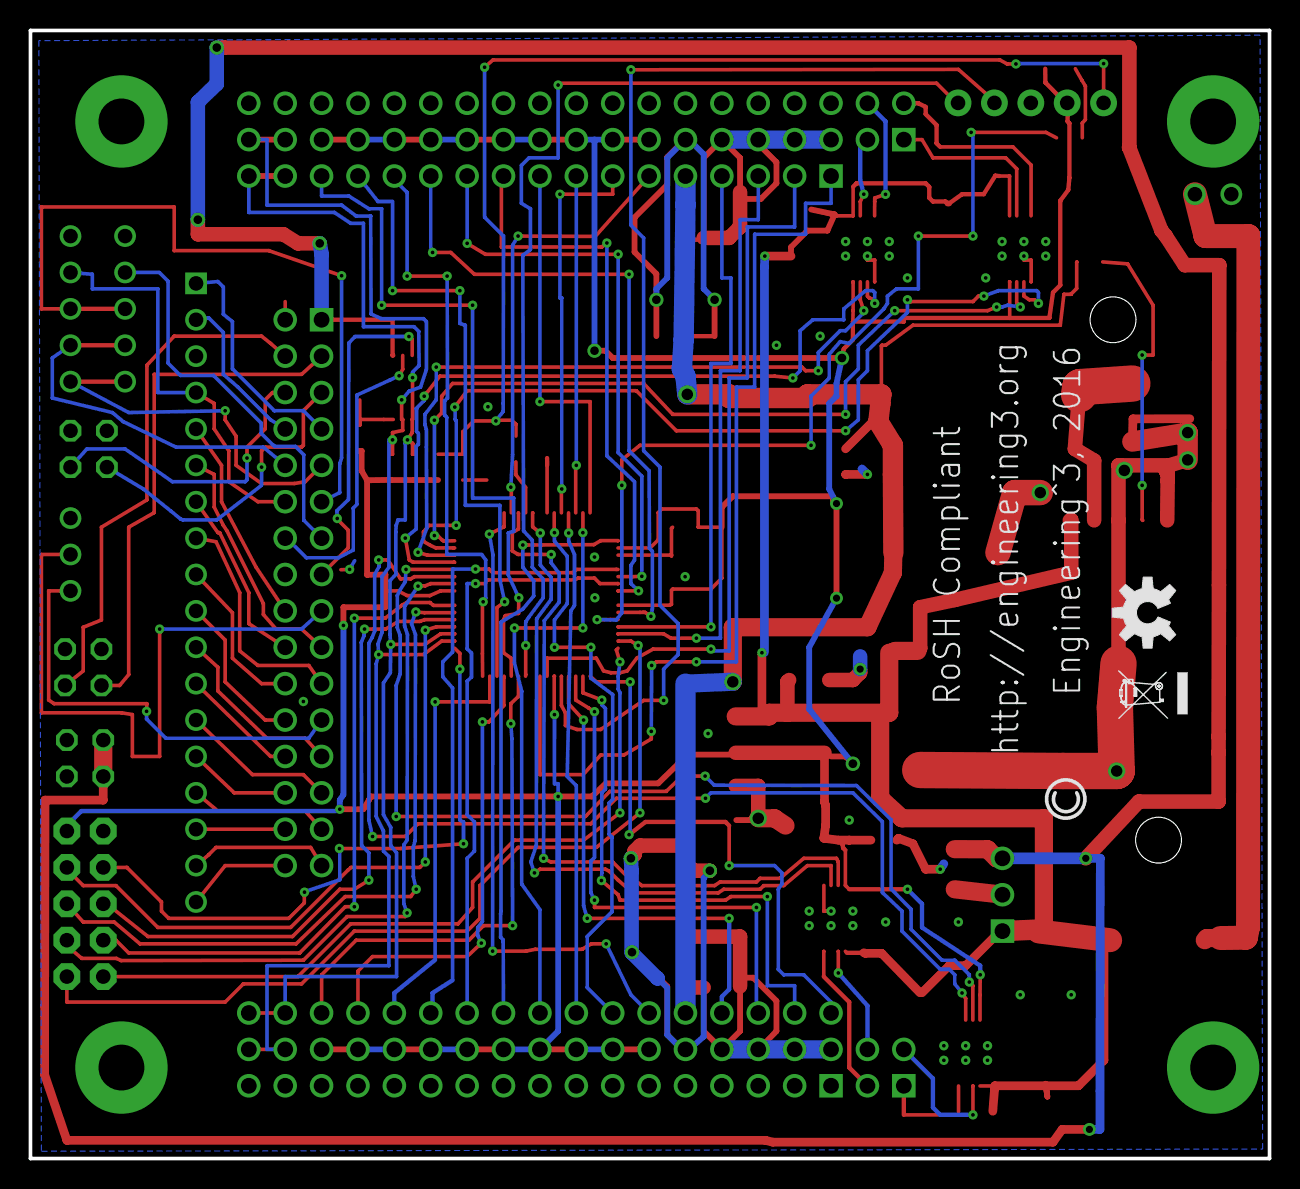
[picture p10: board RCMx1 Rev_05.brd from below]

Board: 2 copper layers, 86.5 x 78.7 mm, 74 parts (2 on the bottom side), 105 nets.

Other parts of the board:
LOGO1: OSHW-LOGOM; OSHW-LOGO-M
U$4: ROHS_GARBAGE_5MM

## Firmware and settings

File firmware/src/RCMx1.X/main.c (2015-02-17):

/******************************************************************************
 * RCMx1 Firmware
 * Written for Tim Jump at Engineering^3
 * By Brian Schmalz of LogicPD
 * July 2012
 * Copyright Engineering^3 2015
 *
 * This firmware runs all of the functions of the RCMx1 I/O expander board
 * The RXMx1 connects to the SRV-1 Surveyor Blackfin Camera board via I2C
 * and listens for commands from the SRV. It has analog inputs, digital I/O,
 * RC Servo outputs, and h-bridge motor driver outputs. It also breaks out all
 * of the SRV-1 bus signals.
 *
 *
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
 * You should have received a copy of the GNU General Public License
 * along with this program; if not, write to the Free Software
 * Foundation, Inc., 51 Franklin Street, Fifth Floor, Boston, MA  02110-1301, USA.
 *****************************************************************************/

/******************************************************************************/
/* Files to Include                                                           */
/******************************************************************************/

#include <p18f86k22.h>
#include <GenericTypeDefs.h>
#include "system.h"        /* System funct/params, like osc/peripheral config */
#include "user.h"          /* User funct/params, such as InitApp */
#include "I2C.h"
#include "interrupts.h"
#include "ADC.h"
#include "timers.h"
#include "PWM.h"

/******************************************************************************/
/* User Global Variable Declaration                                           */
/******************************************************************************/

/******************************************************************************/
/* Main Program                                                               */
/******************************************************************************/

void main(void)
{
    /* Configure the oscillator for the device */
    ConfigureOscillator();

    /* Initialize I/O and Peripherals for application */
    IOInit();

    /* Start up our I2C communications */
    I2CInit();

    /* Start ADC running */
    ADCInit();

    /* Start up timers */
    TimerInit();

    /* Start up PWMs */
    PWMInit();
    
    /* Enable Interrupts */
    InterruptsInit();

    /* Initalize any user application */
    AppInit();

    while(1)
    {
        // Call the main user application loop whenever we have spare tiem
        UserAppRun();
    }
}

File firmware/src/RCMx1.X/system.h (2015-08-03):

/******************************************************************************
 * RCMx1 Firmware
 * Written for Tim Jump at Engineering^3
 * By Brian Schmalz of LogicPD
 * July 2012
 * Copyright Engineering^3 2015
 *
 * This firmware runs all of the functions of the RCMx1 I/O expander board
 * The RXMx1 connects to the SRV-1 Surveyor Blackfin Camera board via I2C
 * and listens for commands from the SRV. It has analog inputs, digital I/O,
 * RC Servo outputs, and h-bridge motor driver outputs. It also breaks out all
 * of the SRV-1 bus signals.
 *
 *
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
 * You should have received a copy of the GNU General Public License
 * along with this program; if not, write to the Free Software
 * Foundation, Inc., 51 Franklin Street, Fifth Floor, Boston, MA  02110-1301, USA.
 *****************************************************************************/

#include <p18f86k22.h>
#include <GenericTypeDefs.h>

#ifndef __SYSTEM_H__
#define __SYSTEM_H__

/******************************************************************************/
/* System Level #define Macros                                                */
/******************************************************************************/

/* TODO Define system operating frequency */

/* Microcontroller MIPs (FCY) */
#define SYS_FREQ                    8000000L
#define FCY                         SYS_FREQ/4

#define OUTPUT                      0
#define INPUT                       1

// What I2C address do we want to respond to?
#define RCMX1_I2C_ADDRESS           0x38

// Our firmware version number (1 byte)
#define RCMX1_FIMRWARE_VERSION      0x13

#define RCMx1_PORTB_MASK            0b00111111
#define RCMx1_PORTB_RBPU_MASK       0b00000001

#define RC_SERVO_COUNT              8

#define GPIO_PULLUP_ENABLE          0
#define GPIO_PULLUP_DISABLE         1

// These must be defined this way so that the default for register 0x24 is 0x00
#define RC_SERVO_ENABLE_OFF         1
#define RC_SERVO_ENABLE_ON          0

// Bit values for register 0x21
#define RC_SERVO_DIRECTION_INPUT    0
#define RC_SERVO_DIRECTION_OUTPUT   1

// Bit values for register 0x25 RC Servo filter enable bits
#define RC_SERVO_FILTER_OFF         0
#define RC_SERVO_FILTER_ON          1

// Bit values for register 0xA1 Analog Input GPIO Direction
#define ANALOG_DIRECTION_OUTPUT     1
#define ANALOG_DIRECTION_INPUT      0

// These values are what the user writes into register 0xA4 Analog Input Enable
#define ANALOG_ENABLE_REGISTER_BIT_ENABLE   0
#define ANALOG_ENABLE_REGISTER_BIT_DISABLE  1

// These values are what get written to the PIC's analog enable register
#define ANALOG_ENABLE               1
#define ANALOG_DISABLE              0

// Default (boot up) value in the Safety Timeout Register (in seconds)
#define DEFAULT_SAFETY_TIMEOUT_S    0

// For debug output bits
#define DEBUG1                      LATCbits.LATC6
#define DEBUG2                      LATCbits.LATC7
#define DEBUG3                      LATDbits.LATD0
#define DEBUG4                      LATDbits.LATD1
#define DEBUG5                      LATDbits.LATD2
#define DEBUG6                      LATDbits.LATD3
#define DEBUG7                      LATDbits.LATD4
#define DEBUG8                      LATDbits.LATD7

#define DEBUG1_TRIS                 TRISCbits.TRISC6
#define DEBUG2_TRIS                 TRISCbits.TRISC7
#define DEBUG3_TRIS                 TRISDbits.TRISD0
#define DEBUG4_TRIS                 TRISDbits.TRISD1
#define DEBUG5_TRIS                 TRISDbits.TRISD2
#define DEBUG6_TRIS                 TRISDbits.TRISD3
#define DEBUG7_TRIS                 TRISDbits.TRISD4
#define DEBUG8_TRIS                 TRISDbits.TRISD7

// Define our pins
#define RCSERVO1_PIN                PORTCbits.RC2       // RC_SERVO_1
#define RCSERVO2_PIN                PORTCbits.RC3       // RC_SERVO_2
#define RCSERVO3_PIN                PORTCbits.RC4       // RC_SERVO_3
#define RCSERVO4_PIN                PORTCbits.RC5       // RC_SERVO_4
#define RCSERVO5_PIN                PORTAbits.RA6       // RC_SERVO_5
#define RCSERVO6_PIN                PORTAbits.RA7       // RC_SERVO_6
#define RCSERVO7_PIN                PORTCbits.RC0       // RC_SERVO_7
#define RCSERVO8_PIN                PORTCbits.RC1       // RC_SERVO_8

#define RCSERVO1_TRIS               TRISCbits.TRISC2    // RC_SERVO_1
#define RCSERVO2_TRIS               TRISCbits.TRISC3    // RC_SERVO_2
#define RCSERVO3_TRIS               TRISCbits.TRISC4    // RC_SERVO_3
#define RCSERVO4_TRIS               TRISCbits.TRISC5    // RC_SERVO_4
#define RCSERVO5_TRIS               TRISAbits.TRISA6    // RC_SERVO_5
#define RCSERVO6_TRIS               TRISAbits.TRISA7    // RC_SERVO_6
#define RCSERVO7_TRIS               TRISCbits.TRISC0    // RC_SERVO_7
#define RCSERVO8_TRIS               TRISCbits.TRISC1    // RC_SERVO_8

#define ANALOG1_PIN                 PORTGbits.RG1       // LCA_L1
#define ANALOG2_PIN                 PORTFbits.RF7       // LCA_L2
#define ANALOG3_PIN                 PORTFbits.RF5       // LCA_L3
#define ANALOG4_PIN                 PORTFbits.RF3       // LCA_L4
#define ANALOG5_PIN                 PORTFbits.RF1       // LCA_L5
#define ANALOG6_PIN                 PORTAbits.RA1       // HCA_L1
#define ANALOG7_PIN                 PORTAbits.RA3       // HCA_L2
#define ANALOG8_PIN                 PORTGbits.RG2       // LCA_R1
#define ANALOG9_PIN                 PORTFbits.RF6       // LCA_R2
#define ANALOG10_PIN                PORTFbits.RF4       // LCA_R3
#define ANALOG11_PIN                PORTFbits.RF2       // LCA_R4
#define ANALOG12_PIN                PORTAbits.RA0       // HCA_R1
#define ANALOG13_PIN                PORTAbits.RA2       // HCA_R2
#define ANALOG14_PIN                PORTAbits.RA5       // HCA_R3

#define ANALOG1_TRIS                TRISGbits.TRISG1    // LCA_L1
#define ANALOG2_TRIS                TRISFbits.TRISF7    // LCA_L2
#define ANALOG3_TRIS                TRISFbits.TRISF5    // LCA_L3
#define ANALOG4_TRIS                TRISFbits.TRISF3    // LCA_L4
#define ANALOG5_TRIS                TRISFbits.TRISF1    // LCA_L5
#define ANALOG6_TRIS                TRISAbits.TRISA1    // HCA_L1
#define ANALOG7_TRIS                TRISAbits.TRISA3    // HCA_L2
#define ANALOG8_TRIS                TRISGbits.TRISG2    // LCA_R1
#define ANALOG9_TRIS                TRISFbits.TRISF6    // LCA_R2
#define ANALOG10_TRIS               TRISFbits.TRISF4    // LCA_R3
#define ANALOG11_TRIS               TRISFbits.TRISF2    // LCA_R4
#define ANALOG12_TRIS               TRISAbits.TRISA0    // HCA_R1
#define ANALOG13_TRIS               TRISAbits.TRISA2    // HCA_R2
#define ANALOG14_TRIS               TRISAbits.TRISA5    // HCA_R3
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

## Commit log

2015-02-14 Initial checkin of files from Logic.
    [RCMX Rev_00.brd, RCMX Rev_00.sch, RCMX Rev_00_BPS.brd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]
2015-02-14 Created new v3 version of the board, added new copyright, license, OSHW, etc. to schematic and board.
    [RCMx1 Rev_03 Bom Costed.xls, RCMx1 Rev_03.brd, RCMx1 Rev_03.sch]
2015-02-16 Fixed some file locations to make things clearer.
    [RCMX Rev_00.brd, RCMX Rev_00.sch, RCMX Rev_00_BPS.brd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]
2015-02-17 Moved firmware files from other repo here.
    [RCMx1 PinTable2.xls]
2015-03-05 Version 0x08 of RCMx1 firmware. * Updated Command document to reflect actual code - marked sections as not implemented and set default values to be 0x00 * Updated firmware to match command document, 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
    [RCMx1 Rev_03.sch]
2015-03-11 Fixed some minor consistency issues in the RCMx1 Commands document.
    [system.c]
2015-03-19 Tim found a bug with H-Bridge motor output A (it acted backwards from the other 3). This has now been fixed and tested. Bumped version number to 0x0A.
    [PWM.c, system.h]
2015-03-22 Now at version 0x0B. Fixed a bug where we were using inverted bits to initialize the analog enable bits.
    [system.h]
2015-04-18 Version 0x0D. Got all of the RC Servo 'filter' functions working properly (I think). Needs more testing by Tim. Updated commands.txt document to reflect RC servo filter implementation.
2015-04-19 Version 0x0E : Re-wrote safety timeout system
    We now have a single safety timeout value register, and any read/write from the whole RCMx1 board will reset the timer. Updated commands.txt to reflect this.
    [interrupts.c, system.h, timers.c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]
2015-05-09 New version 0x0F: Fixed bug with RC Servo channels - in several previous versions (at least 0x0D and 0x0E) if you ever sent 0x00 to a RC servo channel, it would stay off forever even if you sent vali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
    [interrupts.c, system.h]
2015-07-28 Fixed bug reading analog input pin 10 as digital input. Updated documentation (clarified analog input GPIO register details, and removed extra safety timeout registers that are no longer used. Create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
    [interrupts.c, system.c, system.h]
2015-08-01 Version 0x11 released: Instead of shutting off RC servo outputs when safety timeout expires, we now 'center' them at 1.5ms pulses (0x80)
2015-08-02 Version 0x12 : Changed safety timeout to ONLY be reset with read/write of register 0x0F. This prevents streaming sensors from LabView from constantly resetting the safety timeout value.
    [interrupts.c, system.h, user.c]
2015-08-03 Version 0x13: Changed Safety Timeout so that when it trips, we set all DC motor outputs to 'brake' (i.e. 0x80) rather than 'coast' (0x00).
2016-02-29 Created version 04 of RCMx1 board - silk screen layer changes only, no component, schematic, or other board changes.
    [RCMx1 Rev_04 BOM.xls, RCMx1 Rev_04.brd, RCMx1 Rev_04.sch]
2016-02-29 Rotated board name on top silk layer 180 degrees.
    [RCMx1 Rev_04.brd, RCMx1 Rev_04.sch]
2016-03-01 Added RCMx1 Rev_04 gerbers (OSH Park CAM)
    [RCMx1 Rev_04.drills.xln]
2016-03-05 Updated BOM for v04 : updated connectors to be gold plated.
    [RCMx1 Rev_04 BOM.xls]
2016-07-31 Removed text in bottom copper layer
    [RCMX Rev_00.brd, RCMX Rev_00_BPS.brd, RCMX Rev_00_BPS2.brd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]
2016-07-31 * Created gerbers from updated Eagle board files
    [RCMX Rev_01.brd, RCMx1 Rev_03.brd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]
2016-08-01 Added board build readme.
2016-09-05 Added PDFs of schematic and board layout for rev 04
2016-11-30 Created RCMx1 rev 05 - fixed pin 1 silk screen designator for J7
    [RCMx1 Rev_05 BOM.xls, RCMx1 Rev_05.brd, RCMx1 Rev_05.sch]
2018-03-20 Fixed spelling on bottom silk layer.
    [RCMx1 Rev_05.brd]
2019-05-12 Updated pin chart to reflect unused timer channel gate pin and four interrupt pins.
    [RCMx1 PinTable2.xls]
2019-05-20 Moved docs file
    [RCMx1 PinTable2.xls]
2020-01-17 Updated RCMx1_Commands.txt with detailed timing information about the RC servo outputs.

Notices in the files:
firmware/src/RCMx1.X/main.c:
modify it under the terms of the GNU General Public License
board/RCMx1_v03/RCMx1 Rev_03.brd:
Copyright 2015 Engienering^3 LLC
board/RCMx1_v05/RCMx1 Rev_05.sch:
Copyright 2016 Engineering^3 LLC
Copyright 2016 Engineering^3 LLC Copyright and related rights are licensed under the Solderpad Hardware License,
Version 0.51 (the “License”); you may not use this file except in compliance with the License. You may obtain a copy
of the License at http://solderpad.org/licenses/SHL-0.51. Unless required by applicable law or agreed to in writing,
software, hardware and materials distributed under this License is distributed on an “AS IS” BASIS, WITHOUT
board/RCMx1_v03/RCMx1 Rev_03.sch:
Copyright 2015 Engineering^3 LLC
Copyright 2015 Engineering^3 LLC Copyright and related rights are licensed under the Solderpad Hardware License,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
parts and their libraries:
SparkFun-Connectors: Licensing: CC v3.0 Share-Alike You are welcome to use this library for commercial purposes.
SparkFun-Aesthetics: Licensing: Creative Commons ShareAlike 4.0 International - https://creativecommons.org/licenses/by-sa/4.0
